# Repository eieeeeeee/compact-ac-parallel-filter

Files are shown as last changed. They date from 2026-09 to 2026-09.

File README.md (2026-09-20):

# Compact AC Parallel Filter

Compact plug-in experimental AC mains parallel network for **100 V AC, 50/60 Hz** environments.

> [!WARNING]
> ## PRE-PROTOTYPE / EXPERIMENTAL / NOT YET TESTED ON MAINS
>
> This project is currently at the **design and simulation stage only**.
>
> **No physical prototype has yet been manufactured or tested.**
>
> The schematic, PCB layout, component selection, insulation distances, enclosure, thermal behavior, surge behavior, failure modes, and noise-reduction performance have **not yet been validated on actual mains power**.
>
> This repository must **not** be interpreted as a finished, certified, production-ready, or safety-approved design.
>
> The design connects directly to hazardous mains voltage. Construction, testing, modification, or use should only be undertaken by persons with appropriate electrical-safety knowledge, equipment, and applicable regulatory review.

## Status

| Item | Current state |
|---|---|
| Version | `v0.1.1-preprototype` |
| Development stage | Design / simulation / pre-prototype |
| Target mains | 100 V AC, 50/60 Hz |
| KiCad 10 review PCB | **DRC: 0 violations / 0 unconnected pads / 0 footprint errors** |
| Physical prototype | **NOT BUILT** |
| Mains test | **NOT PERFORMED** |
| EMI/noise performance | **NOT VERIFIED** |
| Thermal test | **NOT PERFORMED** |
| Surge/fault test | **NOT PERFORMED** |
| Safety certification | **NONE** |

## Latest review material

- [KiCad hardware files](hardware/kicad/README.md)
- [KiCad 10 review PCB v0.5](hardware/kicad/review-v0.5/README.md) — 50 × 35 mm spacing/DNP study
- [KiCad 10 official DRC report](measurements/drc/DRC_KiCad10_v0_5_20260920.rpt)
- [Simulation v0.1](simulations/v0.1/simulation_assumptions_v0_1.md)
- [Editable LTspice analysis files](simulations/ltspice-v0.1/README.md) — AC sweep and post-unplug discharge
- [Simulation overview image](images/shunt_filter_simulation_overview_v0_1.png)

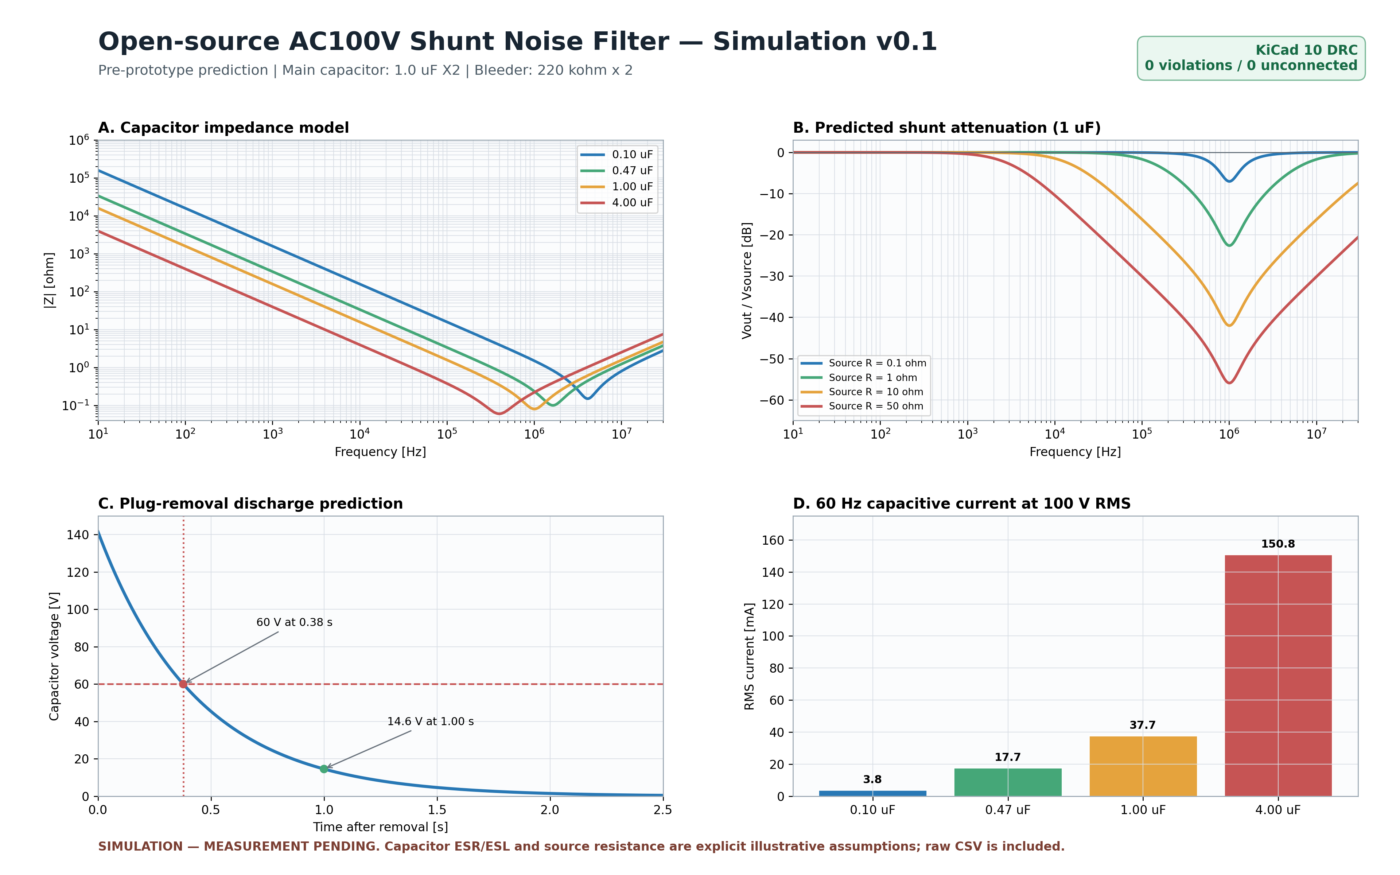
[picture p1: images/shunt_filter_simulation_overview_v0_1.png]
Pre-prototype simulation overview


The simulation figures are **predictions based on disclosed assumptions**, not measurements. In particular, high-frequency performance depends on capacitor ESR/ESL, PCB and wiring inductance, outlet/source impedance, connected equipment, and placement.

## Design target

The initial concept is a compact direct plug-in parallel network using:

- **C1:** 1 µF X2 safety capacitor — KEMET R53 series
- **R1/R2:** 220 kΩ + 220 kΩ discharge network
- **F1:** Littelfuse 37402500000, 250 mA time-lag fuse
- **MOV1:** Littelfuse TMOV14RP140E thermally protected MOV
- **LED:** low-current status indicator with reverse-voltage protection
- **CMC:** not included in the initial parallel-only architecture
- **Optional C2 / RC damping:** reserved for later measurement-based evaluation

Two PCB studies are retained for review rather than silently replacing one another:

| Revision | Board | Purpose |
|---|---:|---|
| KiCad 9 Rev.A | 32 × 28 mm | compact mechanical study |
| KiCad 10 review v0.5 | 50 × 35 mm | wider spacing and DNP comparison footprints |

Neither revision is a fabrication-approved or mains-validated design.

## Project goals

1. Design the smallest practical direct plug-in PCB without sacrificing electrical-safety margins.
2. Publish the complete design process, not only favorable results.
3. Measure the effect of the network under controlled conditions.
4. Record temperature, discharge behavior, mains current, noise spectra, and failure-related observations.
5. Revise the PCB based on measured data before calling the design validated.

## Repository structure

```text
.
├─ README.md
├─ SAFETY.md
├─ CHANGELOG.md
├─ LICENSE
├─ bom/
│  └─ BOM.md
├─ docs/
│  ├─ DESIGN_NOTES.md
│  └─ TEST_PLAN.md
├─ hardware/
│  └─ kicad/
│     ├─ README.md
│     └─ review-v0.5/
├─ simulations/
│  └─ v0.1/
├─ measurements/
│  ├─ README.md
│  └─ drc/
└─ images/
```

## Development stages

### v0.1 — Pre-prototype

- schematic development
- BOM definition
- PCB layout
- enclosure study
- creepage/clearance review
- design review before manufacturing

### v0.2 — Prototype

- first PCB manufactured
- visual inspection
- continuity/isolation checks
- controlled first power-up
- mechanical fit evaluation

### v0.3 — Measurement

- mains current
- discharge time
- thermal measurements
- oscilloscope measurements
- conducted-noise comparison
- before/after data under repeatable loads

### v0.4 — Revised prototype

PCB and BOM revised from measured results.

### v1.0 — Validated open-hardware release

Only after the defined validation work has been completed and the published documentation reflects the tested hardware revision.

## Measurement policy

Negative or null results are still results.

The project intends to publish comparable measurements for:

- baseline without the network
- 1 µF network enabled
- representative resistive/electronic loads
- 50 Hz and 60 Hz where practical
- temperature and long-duration behavior
- noise spectra using identical measurement settings

No performance claim should be made from the circuit diagram or simulation alone.

## Regulatory note

Open-source publication does **not** imply compliance with Japanese PSE requirements, IEC standards, or any other product-safety or EMC requirement. Regulatory compliance, certification, and marketability are separate questions from publication of design files.

See [SAFETY.md](SAFETY.md) before working with this design.

---

## 日本語概要

このリポジトリは、AC100 Vコンセントに直接挿す小型並列回路の**設計・計算・測定過程を公開する実験的オープンハードウェアプロジェクト**です。

**現時点では実機未製作・商用電源未試験です。完成品、安全確認済み製品、認証済み製品ではありません。**

KiCad 10用レビュー基板v0.5では公式DRCを実行し、違反0・未接続0・フットプリントエラー0を確認しました。ただし、DRC合格は回路の安全性、部品定格、絶縁、筐体、熱、サージ耐性、ノイズ低減効果を保証するものではありません。

試作前のシミュレーションでは、容量別インピーダンス、電源側インピーダンス別の減衰予測、1 µF＋440 kΩの放電曲線、AC100 V・60 Hz時の容量電流を公開しています。使用した仮定と計算用データも収録し、試作後に実測値と比較できる形にしています。

初号機を製作・測定するまでは `v0.1.1-preprototype` として扱い、実測結果は成功・不成功を問わず公開する方針です。

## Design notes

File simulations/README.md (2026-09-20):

# Simulations

Pre-prototype calculations and transparent model inputs are stored here.

## v0.1

The first dataset compares:

- impedance of 0.1 µF, 0.47 µF, 1 µF and 4 µF capacitor models
- predicted shunt attenuation for several assumed source impedances
- ideal discharge of 1 µF through 440 kΩ
- 60 Hz capacitive current at 100 V RMS

Start with [`v0.1/simulation_assumptions_v0_1.md`](v0.1/simulation_assumptions_v0_1.md) and the [overview image](../images/shunt_filter_simulation_overview_v0_1.png).

These are calculations, not measured product-performance claims. Raw CSV data, the generation script and LTspice-compatible example netlists are included for review and reproduction.

## LTspice v0.1

Editable LTspice analysis files are available in [`ltspice-v0.1/`](ltspice-v0.1/README.md):

- small-signal AC sweep with stepped source impedance
- ideal post-unplug discharge of 1 µF through 440 kΩ

The `.asc` files expose every model assumption as a SPICE directive and can be changed before rerunning the analysis.

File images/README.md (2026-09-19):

# Images

Planned contents:

- schematic preview
- PCB render
- enclosure concept
- assembled prototype photographs
- test setup photographs

Any rendered PCB or enclosure image must be clearly distinguishable from a photograph of a tested prototype.

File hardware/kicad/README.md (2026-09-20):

# KiCad hardware

This directory contains two editable PCB studies. They are kept as separate revisions because their board size and implementation choices differ.

## Revision index

| Revision | KiCad | Board | Purpose | Status |
|---|---:|---:|---|---|
| Rev.A | 9 | 32 × 28 mm | compact mechanical study | pre-prototype |
| [review-v0.5](review-v0.5/README.md) | 10 | 50 × 35 mm | spacing and optional DNP branch study | official DRC: 0 violations |

Neither revision has been manufactured or tested on mains.

## Rev.A files in this directory

- `compact-ac-parallel-filter.kicad_pro` — project
- `compact-ac-parallel-filter.kicad_sch` — schematic
- `compact-ac-parallel-filter.kicad_pcb` — exact 32 × 28 mm PCB outline
- `ACP.kicad_sym` — local symbols
- `ACP.pretty/` — project-local footprints
- `PLACEMENT.csv` — placement coordinates

## Status

**PRE-PROTOTYPE / NOT YET TESTED ON MAINS.**

These files are for design review before fabrication. No physical-fit, mains, thermal, surge, EMC, PSE, or third-party safety validation has been completed.

## Rev.A mechanical basis

- PCB: **32.0 × 28.0 mm**
- nominal PCB thickness: **1.6 mm**
- C1: 22.5 mm lead pitch, 26.5 × 10 mm top-view body envelope
- MOV1: 7.5 mm nominal lead spacing; the footprint reserves a **17 mm maximum body envelope**
- F1: 5.08 mm pitch, 8.5 mm diameter envelope
- large THT parts are on the front; low-power resistor/LED/diode parts are on the back

At 32 × 28 mm the large-part courtyards are deliberately packed to the mechanical limit. If final creepage, clearance, enclosure or tolerance review fails, increase the PCB size rather than reducing safety margin.

## J1 limitation

`J1` is **not a Japanese/Type-A plug-blade footprint**. It is a provisional electrical interface to a separately mechanically retained plug assembly. Plug insertion/removal force must not be carried only by the PCB pads.

## Before ordering

1. Choose one reviewed hardware revision; do not mix files from different revisions.
2. Apply the final mains creepage/clearance rules for the actual regulatory environment.
3. Verify enclosure and component maximum dimensions against manufacturer drawings.
4. Verify every resistor's working/pulse voltage, power and flame behavior.
5. Verify the final LED and diode part numbers.
6. Replace J1 with the final plug/enclosure mechanical interface.
7. Review fuse/MOV coordination and abnormal-condition behavior.
8. Run ERC/DRC again with the exact ordered components and manufacturing rules.

## Rev.A topology

```text
AC L -- F1 --+-- C1 1uF X2 --+-- N
             |                |
             +-- MOV1 --------+
             |                |
             +-- R1 -- R2 ----+
             |                |
             +-- R4 -- R5 -- LED1 --+
                              |      |
                              +--D1--+  reverse clamp
                                     |
                                     N
```

C2 and optional RC damping are intentionally not implemented on the 32 × 28 mm Rev.A PCB. The 50 × 35 mm review-v0.5 board provides DNP footprints for measurement-driven comparison.

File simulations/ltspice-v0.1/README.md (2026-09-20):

# LTspice simulation v0.1

This folder contains editable LTspice analysis sheets for reproducing two pre-prototype calculations.

## Files

- `shunt_filter_ac_v0_1.asc` — small-signal AC sweep of the 1 µF shunt branch
- `discharge_v0_1.asc` — ideal post-unplug discharge of 1 µF through 440 kΩ

Both files are plain-text LTspice `.asc` sheets. The circuit is defined by visible SPICE directives so that the assumed values can be reviewed and edited directly.

## 1. AC sweep

Open `shunt_filter_ac_v0_1.asc`, click **Run**, and plot:

```text
dB(V(vout)/V(vin))
```

The source resistance is stepped through:

```text
0.1 Ω, 1 Ω, 10 Ω, 50 Ω
```

The capacitor model is:

```text
C = 1 µF
ESR = 0.08 Ω
ESL = 25 nH
```

These ESR and ESL values are illustrative assumptions, not guaranteed KEMET R53 data. Replace them with measured impedance or manufacturer frequency data when available.

The 50 Ω curve is a repeatable test-fixture case. It does not mean that a household outlet has 50 Ω source impedance. Real attenuation depends on the noise source impedance, house wiring, connected equipment, placement and frequency.

The fuse, TMOV and LED branch are omitted from this linear small-signal model. Their primary roles are protection and indication; the MOV is normally non-conductive at the AC test amplitude.

## 2. Discharge

Open `discharge_v0_1.asc`, click **Run**, and plot:

```text
V(cap)
```

Nominal model:

- initial voltage: 141.421 V, equal to the peak of 100 V RMS
- C1: 1 µF
- Rbleed: 440 kΩ
- time constant: 0.44 s
- predicted crossing of 60 V: approximately 0.377 s
- predicted voltage at 1 s: approximately 14.6 V

The model is ideal and does not include component tolerance, resistor voltage coefficient, interruption phase, instrument loading or external coupling.

## Scope and safety

These files are simulations only. They do not demonstrate EMI performance, surge protection, regulatory compliance or safe mains construction. The hardware remains unbuilt and untested on mains.

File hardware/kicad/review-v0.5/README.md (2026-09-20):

# KiCad 10 review PCB v0.5

This folder contains a separate **50 × 35 mm** pre-prototype PCB study for electrical-spacing review and later A/B measurements. It does not replace the 32 × 28 mm KiCad 9 Rev.A design.

## Files

- `wall_filter_v0_5.kicad_pcb` — routed KiCad 10 PCB
- `wall_filter_v0_5.kicad_dru` — project design rules
- `fp-lib-table` — project-local footprint mapping
- `WallFilter_Custom.pretty/` — 12 local footprints
- `PCB_NOTES_v0_5.md` — revision notes and DRC summary
- `STATIC_CHECK_v0_5.txt` — independent static geometry/connectivity check

The official KiCad 10 DRC output is archived at [`measurements/drc/DRC_KiCad10_v0_5_20260920.rpt`](../../../measurements/drc/DRC_KiCad10_v0_5_20260920.rpt).

## Verification snapshot

KiCad 10 official DRC, 2026-09-20:

- DRC violations: **0**
- unconnected pads: **0**
- footprint errors: **0**

Static checker:

- pads checked: 26
- routed segments checked: 23
- reported minimum L/L_FUSED-to-N copper spacing: 4.5 mm
- reported minimum copper-to-rectangular-board-boundary distance: 2.0 mm

These checks verify the rules and geometry represented in the files; they do **not** establish regulatory compliance or safety on mains.

## Implemented branches

- fused L input
- C1: 1 µF X2 main shunt capacitor
- R1 + R2: 220 kΩ + 220 kΩ discharge chain
- MOV1: 140 VAC thermally protected MOV candidate
- low-current LED branch and antiparallel protection diode
- C2: optional 0.1 µF X2 footprint, **DNP initially**
- R3/C3: optional series RC damping footprint, **DNP initially**

## Required review before fabrication or energization

- Match every footprint to the exact manufacturer drawing and ordered part.
- Confirm voltage, pulse, power, flammability and safety approvals for each part.
- Review creepage/clearance for the final material, pollution degree, enclosure and applicable standard.
- Finalize plug blades, retention, enclosure, insulation and accessible-part protection as one mechanical system.
- Review fuse clearing and TMOV coordination under credible faults.
- Perform unpowered continuity/insulation checks before any controlled mains test.

**PRE-PROTOTYPE / NOT YET BUILT / NOT YET TESTED ON MAINS.**

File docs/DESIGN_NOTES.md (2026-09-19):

# Design Notes

## Project architecture

The initial version is a **direct plug-in parallel network** connected across 100 V AC mains.

It is not a pass-through power filter and has no downstream outlet or load path.

## Preliminary topology

After the input fuse, the following branches are intended to be connected across line and neutral:

- 1 µF X2 capacitor
- 220 kΩ + 220 kΩ discharge resistor chain
- thermally protected MOV
- low-current indicator LED branch
- optional DNP X2 capacitor footprint
- optional DNP RC damping footprint

## Why no CMC in v0.1

A conventional common-mode choke is normally placed in series with line and neutral feeding a load. In the present one-port parallel-only architecture there is no downstream current path through such a choke.

Therefore a CMC is intentionally omitted from the first design.

## Mechanical target

### PCB

Target: **approximately 32 × 28 mm**

This is a size goal, not a mandatory limit.

The PCB must be enlarged if necessary to satisfy:

- creepage/clearance requirements
- component body spacing
- fuse/MOV placement
- thermal behavior
- routing
- manufacturing tolerances
- plug mechanics

### Enclosure

Target: **approximately 38 × 34 × 27 mm**

The enclosure is expected to use vertical component volume efficiently because the X2 capacitor and 14 mm MOV are physically larger than most remaining parts.

## Component placement priorities

1. Fuse near the mains input.
2. MOV electrically after the fuse.
3. Keep high-current surge paths short.
4. Place C1 and its discharge resistors close together.
5. Keep mains-connected copper away from enclosure openings and accessible surfaces.
6. Do not use dense copper pours merely to reduce routing length.
7. Reserve sufficient edge spacing around the PCB perimeter.

## Electrical observations

A 1 µF capacitor across 100 V AC carries a nominal reactive current of approximately:

- 31 mA at 50 Hz
- 38 mA at 60 Hz

This is reactive current, not equivalent real power dissipation, but it is relevant to component stress and circuit behavior.

## Version policy

The project remains **pre-prototype** until a physical unit is assembled.

No efficiency, EMI-reduction, surge-protection, thermal, or safety-performance claim should be made before measurement.

## KiCad Rev.A implementation

The first editable PCB study is committed under `hardware/kicad/`.

### Exact board outline

**32.0 × 28.0 mm**, nominal 1.6 mm FR-4.

### Placement strategy

Front side:
- C1 — KEMET R53 1 µF X2
- MOV1 — TMOV14RP140E
- F1 — Littelfuse 37402500000
- J1 — provisional connection pads to a separately retained plug assembly

Back side:
- R1/R2 — discharge network
- R4/R5 — LED current limiting
- LED1
- D1 — reverse clamp

Moving the low-power components to B.Cu is what makes the 32 × 28 mm target mechanically plausible.

### Mechanical limit

The C1 courtyard and the 17 mm maximum TMOV body courtyard are effectively packed to the board-size limit. The 32 × 28 mm outline is therefore a **fit study, not a guaranteed production envelope**.

### Plug interface

The current J1 footprint is deliberately not presented as a Japanese Type-A blade footprint. The final plug blade geometry, blade retention and enclosure must be selected as one mechanical system. Plug insertion/removal forces must not rely only on soldered PCB pads.

### Parts still requiring qualification

- exact 220 kΩ 1206 resistor
- exact 47 kΩ 1206 resistor
- exact blue 1206 LED
- exact SOD-123 reverse diode
- final plug/enclosure assembly

The exact resistor parts must satisfy the required voltage, overload/pulse, power and flame-performance requirements for the final product.

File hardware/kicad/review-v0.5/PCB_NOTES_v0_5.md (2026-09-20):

# PCB v0.5 — KiCad 10 DRC警告整理版

## v0.4のKiCad 10公式DRC結果

2026-09-20にKiCad 10で出力されたレポートを確認しました。

- DRCエラー：0
- 未接続パッド：0
- フットプリントエラー：0
- 警告：28

28件は、基板端または銅箔と重なるシルク、シルク同士の重なり、および `Custom` フットプリントライブラリ未登録に関するものでした。電気配線のエラーは報告されていません。

## v0.5の変更点

- `WallFilter_Custom.pretty` に12個のプロジェクト専用フットプリントを収録
- `fp-lib-table` で上記ライブラリを `${KIPRJMOD}` 相対パス登録
- 部品外形線をF.SilkS/B.SilkSからF.Fab/B.Fabへ移動
- 重なっていた部品参照文字を非表示化
- 回路・ネット・部品位置・銅箔配線・基板外形はv0.4から変更なし
- v0.5静的検査：PASS

## 次の確認

1. `wall_filter_v0_5.kicad_pcb` をKiCad 10で開く
2. プロジェクト・フットプリント・ライブラリの登録を求められた場合はプロジェクト固有として承認
3. 「検査」→「デザインルールチェッカー」→「DRCを実行」
4. エラー、警告、未接続が0であることを確認
5. 新しいDRCレポートを保存

v0.5の静的検査では、全26パッドの接続、異ネット銅箔の非重複、L/L_FUSED-N最小4.5mm、銅箔-基板端最小2.0mmを確認しています。KiCad 10公式DRCの再実行をもって警告整理の最終確認とします。

## KiCad 10公式DRC再確認

2026-09-20 11:06（JST）に `wall_filter_v0_5.kicad_pcb` の公式DRCを再実行しました。

- DRC違反：0
- 未接続パッド：0
- フットプリントエラー：0

これにより、v0.5はKiCad 10のDRC確認を通過しました。次工程は、実部品データシートとの外形・定格照合、シミュレーション、筐体干渉確認、試作後の通電前検査です。

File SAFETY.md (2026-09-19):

# Safety

## Hazardous mains voltage

This project is intended to connect directly to **100 V AC mains**. Mains voltage can cause electric shock, burns, fire, equipment damage, or death.

This repository is currently **pre-prototype**. No physical unit has yet been built or validated.

## Current project status

- Physical prototype: **not built**
- Mains powered test: **not performed**
- Thermal test: **not performed**
- Surge/fault test: **not performed**
- Insulation verification: **not completed on hardware**
- Regulatory compliance: **not established**
- Safety certification: **none**

Do not treat any schematic, PCB, BOM, enclosure dimension, or layout in this repository as inherently safe merely because it is published here.

## Design rules for the project

The following are project requirements, not a certification statement:

1. Do not reduce creepage or clearance merely to meet the nominal 32 × 28 mm PCB target.
2. If adequate spacing cannot be maintained, increase the PCB or enclosure size.
3. Keep exposed mains-connected copper inaccessible in the completed enclosure.
4. The plug structure must carry insertion/removal forces mechanically; the PCB should not be used as the sole structural support for plug blades.
5. Use only appropriately rated components for mains-connected positions.
6. Do not substitute ordinary capacitors for X-class safety capacitors.
7. Review fuse and MOV coordination before prototype power-up.
8. Verify discharge voltage after unplugging.
9. Perform first energization using appropriate current limiting, protection, isolation strategy, and test equipment suitable for mains work.
10. Treat oscilloscope grounding and other earth-referenced instruments as potential short-circuit hazards when measuring non-isolated mains circuitry.

## Enclosure

The target enclosure size is approximately **38 × 34 × 27 mm**, but size is secondary to:

- creepage and clearance
- insulation
- flame resistance
- mechanical plug retention
- component temperature
- user inaccessibility to live parts

## Regulatory note

This repository does not claim conformity with PSE, IEC, JIS, UL, CE, or other standards. If the design is ever manufactured, distributed, or sold, the applicable legal and technical requirements must be determined separately.

## Responsibility

Anyone building or modifying this design is responsible for performing their own engineering, safety, and regulatory review.

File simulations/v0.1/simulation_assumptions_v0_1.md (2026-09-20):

# Simulation v0.1 — assumptions and interpretation

## Status

These figures are pre-prototype calculations, not measured performance. They are intended to expose the model and invite review before parts are ordered. The final repository will retain these predictions alongside measured results.

## Capacitor impedance model

Each capacitor is represented by an ideal capacitance in series with illustrative ESR and ESL:

| Nominal capacitance | ESR | ESL |
|---:|---:|---:|
| 0.10 µF | 0.15 Ω | 15 nH |
| 0.47 µF | 0.10 Ω | 20 nH |
| 1.00 µF | 0.08 Ω | 25 nH |
| 4.00 µF | 0.06 Ω | 40 nH |

These are transparent engineering assumptions, not guaranteed values for the selected KEMET R53 part. They must be replaced or bounded using measured impedance or manufacturer frequency data.

## Attenuation model

The filter is modeled as a shunt impedance across L-N, driven through a purely resistive Thevenin source impedance of 0.1, 1, 10, or 50 Ω. The predicted voltage ratio is:

`H(f) = Zfilter(f) / (Zsource + Zfilter(f))`

The 50 Ω curve represents a convenient test-fixture condition; it is not a claim that a household outlet has 50 Ω source impedance. Real attenuation depends on wiring, connected equipment, noise-source impedance, placement, and frequency.

## Discharge model

- Supply: 100 V RMS
- Initial capacitor voltage: 141.4 V peak
- C1: 1.0 µF
- Bleeder: 220 kΩ × 2 series = 440 kΩ
- Time constant: 0.44 s
- Ideal exponential discharge: `V(t) = 141.4 exp(-t/0.44)`

Component tolerance, resistor voltage coefficient, interruption timing, and residual source coupling are not included.

## 60 Hz current

The plot uses ideal capacitive current `I = 2πfCV` at 100 V RMS and 60 Hz. It is reactive current, not equivalent to real power consumption.

## Safety scope

Simulation does not establish regulatory compliance or safe construction. Before energized use, the assembled prototype requires enclosure, insulation, strain relief, temperature, abnormal-condition, fuse-clearing, dielectric-strength, and controlled mains-measurement review.

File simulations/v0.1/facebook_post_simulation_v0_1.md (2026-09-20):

# Facebook掲載文案

挿すだけ並列型ノイズフィルターの試作前シミュレーションを公開しました。

今回掲載したのは、0.1µF・0.47µF・1µF・4µFの容量別インピーダンス、1µFを使用した場合の電源側インピーダンス別の減衰予測、プラグを抜いた後の放電曲線、AC100V・60Hzにおける容量電流の比較です。

現在の基準回路は、1µFのX2安全コンデンサー、220kΩ×2本の放電抵抗、ヒューズ、熱保護付きMOV、通電表示回路で構成しています。KiCad 10の基板DRCは、違反0・未接続0・フットプリントエラー0になりました。

掲載値は実測結果ではなく、試作前の予測値です。特に高周波特性は、コンデンサーのESR・ESL、基板配線、コンセント側や接続機器側のインピーダンスによって変化します。そのため、今回使用した仮定と計算用データもGitHubに公開し、試作後は実測値と比較できる形にします。

単に「効果がある・ない」で終わらせず、どの条件で、どの周波数に、どれくらい作用するのかを確認できるオープンハードウェアとして進めたいと考えています。モデルや測定方法についてお気づきの点があれば、ぜひご意見をお願いいたします。

※AC100Vを扱うため、現段階は設計・シミュレーション・安全検証中です。試作後も、絶縁、温度、放電時間、異常時保護などを確認してから通電評価へ進みます。

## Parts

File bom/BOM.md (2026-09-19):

# Preliminary BOM — v0.1.0-preprototype / KiCad Rev.A

**Status:** design-stage BOM only.  
**Prototype manufactured:** no.  
**Mains tested:** no.

| Ref | Part / target specification | Qty | PCB implementation | Status |
|---|---|---:|---|---|
| F1 | Littelfuse **37402500000** | 1 | THT, 5.08 mm pitch | Selected candidate |
| C1 | KEMET **R533N410050P0K** / R53 | 1 | THT, 22.5 mm pitch | Selected |
| R1, R2 | **220 kΩ each** | 2 | **1206 SMD on B.Cu** | Exact mains-qualified part TBD |
| MOV1 | Littelfuse **TMOV14RP140E** | 1 | THT, 7.5 mm nominal pitch | Selected candidate |
| R4, R5 | **47 kΩ each** | 2 | **1206 SMD on B.Cu** | Exact mains-qualified part TBD |
| LED1 | blue LED | 1 | 1206 SMD on B.Cu | Exact part TBD |
| D1 | **1N4148W-class** reverse clamp | 1 | SOD-123 on B.Cu | Exact part TBD |
| J1 | plug-assembly electrical interface | 1 | two THT pads, 10 mm pitch | **Provisional; not plug blades** |
| C2 | 0.1 µF X2 | 0 | no footprint on Rev.A | Future measurement variant |
| R3/C3 | RC damping network | 0 | no footprint on Rev.A | Future measurement variant |
| PCB | FR-4, **32 × 28 mm** | 1 | KiCad Rev.A | Pre-prototype |

## Important BOM limitations

The 1206 resistor footprint is fixed for the current compact layout, but the **actual resistor manufacturer/series is not yet fixed**. The selected components must be checked for working voltage, overload/pulse voltage, power dissipation, flame behavior and applicable approvals before fabrication.

The same applies to LED1 and D1: the footprint and function are defined, but the exact orderable part numbers remain to be selected.

## Discharge network

R1 + R2 = 440 kΩ nominal across C1.

With C1 = 1 µF, the nominal RC time constant is approximately **0.44 s**. Actual post-unplug voltage decay must be measured on the physical prototype.

## Compact Rev.A exclusions

C2 and the optional RC damping branch are intentionally omitted from the 32 × 28 mm PCB. Adding them is deferred until measurements show a reason to do so.

A common-mode choke is not included because this is a one-port parallel architecture rather than a pass-through filter.

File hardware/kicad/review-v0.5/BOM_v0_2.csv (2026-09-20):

Ref | Qty | Initial | Manufacturer | MPN | Value_or_rating | Role | Notes
C1 | 1 | Fitted | KEMET | R533N410050P0K | 1uF X2 310VAC | Main shunt capacitor | 22.5mm lead pitch
R1 R2 | 2 | Fitted | Vishay | PR01000102203JA100 | 220k 1W 5% | Discharge path | Series total 440k
F1 | 1 | Fitted | Littelfuse | 37402500000 | 250mA 250VAC time-lag | Fault isolation | Radial PCB fuse
MOV1 | 1 | Fitted | Littelfuse | TMOV14RP140E | 140VAC thermally protected MOV | Surge protection | Placed after F1
R4 R5 | 2 | Fitted | Vishay | PR01000104702JA100 | 47k 1W 5% | LED current limiting | Series total 94k
D1 | 1 | Fitted | Generic | 1N4007 | 1000V rectifier diode | LED reverse-voltage clamp | Antiparallel with LED1
LED1 | 1 | TBD | TBD | TBD | 3mm blue low-current high-efficiency | Power indication | Keep behind case window
C2 | 1 | DNP | TBD | TBD | 0.1uF X2 305VAC | High-frequency comparison | Populate only after measurement
R3 C3 | 1 set | DNP | TBD | TBD | Measurement-defined | RC damping branch | Values selected from impedance measurement
J1 | 1 | Mechanical TBD | TBD | TBD | Two-blade AC100V plug interface | Final metal blade retention not yet fixed

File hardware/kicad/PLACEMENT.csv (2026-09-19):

Ref | Side | X_mm | Y_mm | Rotation_deg | Footprint | Status
J1 | F | 124.5 | 125.5 | 0 | ACP:AC_Input_Pads_10mm | PROVISIONAL_NOT_BLADE
F1 | F | 123.5 | 115.2 | 0 | ACP:TR5_374_5.08mm | PREPROTO
C1 | F | 116.0 | 105.25 | 0 | ACP:R53_1uF_22.5mm | PREPROTO
MOV1 | F | 108.75 | 119.25 | 0 | ACP:TMOV14_7.5mm | PREPROTO
R1 | B | 106.0 | 102.8 | 0 | ACP:R_1206 | PART_TBD
R2 | B | 112.0 | 102.8 | 0 | ACP:R_1206 | PART_TBD
R4 | B | 106.0 | 107.5 | 0 | ACP:R_1206 | PART_TBD
R5 | B | 112.0 | 107.5 | 0 | ACP:R_1206 | PART_TBD
LED1 | B | 120.0 | 107.5 | 0 | ACP:LED_1206 | PART_TBD
D1 | B | 120.0 | 110.4 | 180 | ACP:D_SOD123 | PART_TBD

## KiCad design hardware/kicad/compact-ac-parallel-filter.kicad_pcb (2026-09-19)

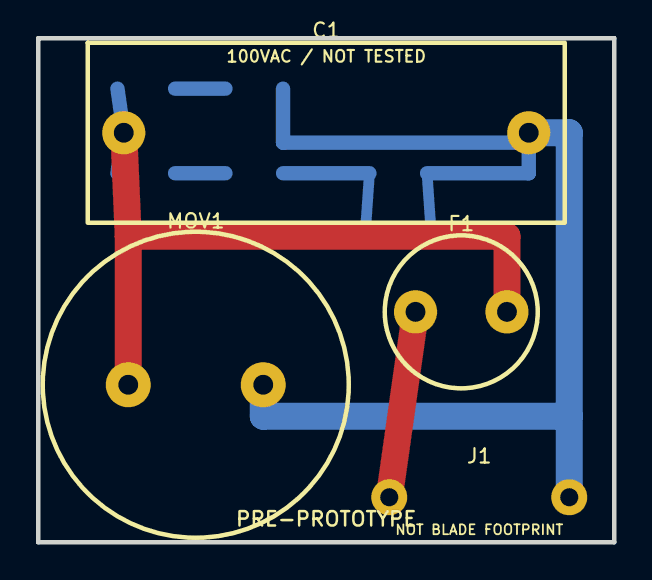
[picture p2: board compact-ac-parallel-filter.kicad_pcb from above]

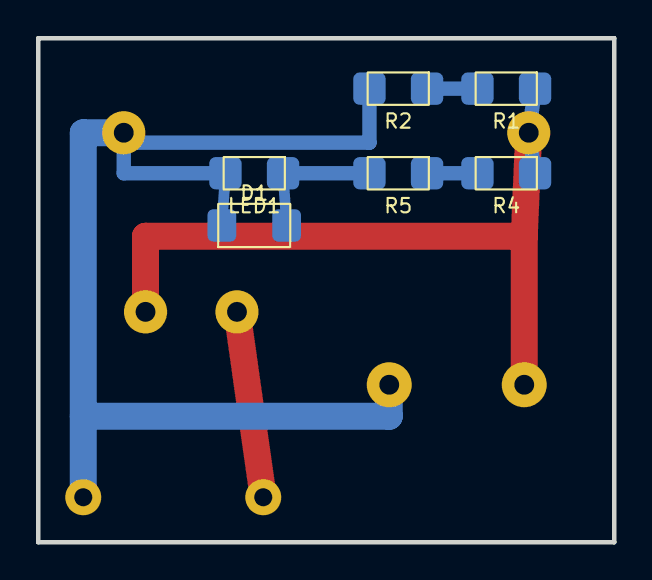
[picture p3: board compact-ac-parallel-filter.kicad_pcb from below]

Board: 2 copper layers, 32.0 x 28.0 mm, 10 parts (6 on the bottom side), 6 nets.

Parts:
C1: R533N410050P0K; R53_1uF_22.5mm
D1: 1N4148W reverse clamp; D_SOD123
F1: 37402500000; TR5_374_5.08mm
J1: PROVISIONAL PLUG INTERFACE; AC_Input_Pads_10mm
LED1: Blue LED; LED_1206
MOV1: TMOV14RP140E; TMOV14_7.5mm
R1, R2: 220k; R_1206
R4, R5: 47k; R_1206

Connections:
AC_L: F1.1, J1.1 (L)
DISCH_MID: R1.2, R2.1
LED_A: D1.2 (K), LED1.1 (A), R5.2
LED_RMID: R4.2, R5.1
L_FUSED: C1.1, F1.2, MOV1.1, R1.1, R4.1
N: C1.2, D1.1 (A), J1.2 (N), LED1.2 (K), MOV1.2, R2.2

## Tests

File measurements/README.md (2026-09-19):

# Measurements

This directory will contain measurements from physical prototypes.

## Current status

**No prototype has been built. No measurements exist yet.**

Planned categories include:

- discharge-voltage measurements
- RMS current
- thermal measurements
- oscilloscope captures
- conducted-noise comparisons
- long-duration observations
- failure or abnormal-behavior reports

Raw data should be retained whenever practical.

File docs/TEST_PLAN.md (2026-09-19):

# Test Plan

## Purpose

This document defines the minimum evidence required before the project can move from **pre-prototype** to a tested hardware revision.

## Stage 0 — Before mains connection

- Visual PCB inspection
- Confirm component values and part numbers
- Verify fuse continuity
- Verify no line-to-neutral hard short
- Verify no accidental copper bridges
- Verify polarity/orientation-sensitive parts
- Verify MOV footprint and pin assignment
- Verify LED protection diode orientation
- Measure resistance across input
- Inspect creepage and clearance against the design review
- Inspect enclosure and plug retention
- Confirm no live conductor can be touched from outside

## Stage 1 — Controlled first energization

Perform only with suitable mains safety equipment and engineering controls.

Record:

- input RMS voltage
- input RMS current
- immediate abnormal heating
- audible noise
- odor/smoke
- LED behavior
- fuse behavior
- voltage across C1

If any abnormal condition occurs, disconnect and document it before revising the design.

## Stage 2 — Discharge test

After disconnecting mains:

- measure voltage versus time
- compare measured decay against the nominal RC model
- repeat over multiple cycles
- document instrument impedance because it can alter the measured discharge

## Stage 3 — Thermal test

Measure temperature of:

- C1
- F1
- MOV1
- R1/R2
- LED resistors
- enclosure internal air
- enclosure external surface

Suggested checkpoints:

- 5 min
- 30 min
- 1 h
- extended run if initial temperatures are stable

Record ambient temperature.

## Stage 4 — Electrical measurements

Measure:

- RMS mains current
- real power if suitable equipment is available
- power factor if suitable equipment is available
- waveform with circuit absent/present
- repeatability over multiple plug-in cycles

## Stage 5 — Noise comparison

The central comparison must use identical measurement settings.

Minimum data sets:

1. baseline — device absent
2. device connected
3. optional C2 fitted, if tested
4. optional RC damping fitted, if tested

Use representative loads, for example:

- no local load / ambient line condition
- switching power supply
- LED lamp
- other repeatable electronic load

For each measurement, record:

- instrument
- probe/coupling method
- bandwidth
- sampling settings
- load
- mains frequency
- time/date
- raw files where possible

## Stage 6 — Mechanical review

Check:

- plug insertion/removal force
- enclosure deformation
- PCB movement
- strain on solder joints
- clearances after assembly
- part movement after repeated plugging cycles

## Stage 7 — Revision decision

A new hardware revision should be created whenever a component value, footprint, routing, spacing, enclosure, or protection strategy changes.

Do not silently modify a tested revision.

## Publication policy

Publish null, negative, and unexpected results as well as favorable results.

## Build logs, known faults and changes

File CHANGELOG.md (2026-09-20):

# Changelog

All notable design changes should be documented here.

## [0.1.1-preprototype] — 2026-09-20

### Added

- Separate KiCad 10 review PCB v0.5 under `hardware/kicad/review-v0.5/`
- Project-local footprint library and design-rule file for v0.5
- Archived official KiCad 10 DRC report
- Simulation v0.1 assumptions, CSV data, plots, generation script and example SPICE netlists
- Simulation overview image for design review
- Editable LTspice `.asc` files for AC sweep and post-unplug discharge analysis
- LTspice instructions, expected nominal checkpoints and model limitations

### Verified

- KiCad 10 v0.5 DRC: 0 violations
- KiCad 10 v0.5 unconnected pads: 0
- KiCad 10 v0.5 footprint errors: 0

### Clarified

- The KiCad 9 Rev.A 32 × 28 mm compact study and KiCad 10 v0.5 50 × 35 mm review study are separate revisions.
- Simulation results are disclosed predictions, not mains measurements or performance certification.
- The project remains pre-prototype and has not been energized on mains.

## [0.1.0-preprototype] — 2026-09-19

### Added

- Initial public repository structure
- Pre-prototype safety notice
- Preliminary BOM
- Design notes
- Prototype test plan
- KiCad workspace placeholder
- Measurement workspace placeholder

### Preliminary design target

- 100 V AC, 50/60 Hz
- PCB target: approximately 32 × 28 mm
- enclosure target: approximately 38 × 34 × 27 mm
- C1: 1 µF X2
- discharge network: 220 kΩ + 220 kΩ
- compact 250 mA time-lag fuse
- thermally protected MOV
- low-current blue status LED
- no CMC in the initial parallel-only topology

### Validation status

No physical prototype has been manufactured or mains-tested.

### KiCad Rev.A 32 × 28 mm hardware added

- Added editable KiCad 9 schematic and PCB
- Fixed PCB outline at 32 × 28 mm for the current mechanical study
- Added project-local symbols and footprints
- Placed C1, MOV1 and F1 on the front
- Moved low-power resistors, LED and clamp diode to B.Cu
- Added placement CSV
- Marked J1 as a provisional plug-assembly interface, not a final blade footprint
- Removed C2/RC footprints from this compact revision pending measurements

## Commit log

2026-09-19 docs: add pre-prototype project README
2026-09-19 docs: add preliminary BOM
2026-09-19 docs: add prototype validation plan
2026-09-19 docs: add KiCad workspace placeholder
2026-09-19 hardware: add compact-ac-parallel-filter.kicad_sch
    [compact-ac-parallel-filter.kicad_sch]
2026-09-19 hardware: add compact-ac-parallel-filter.kicad_pcb
    [compact-ac-parallel-filter.kicad_pcb]
2026-09-19 hardware: add compact-ac-parallel-filter.kicad_pro
2026-09-19 hardware: add ACP.kicad_sym
2026-09-19 hardware: add PLACEMENT.csv
    [PLACEMENT.csv]
2026-09-19 hardware: add R53_1uF_22.5mm.kicad_mod
2026-09-19 hardware: add TMOV14_7.5mm.kicad_mod
2026-09-19 hardware: add TR5_374_5.08mm.kicad_mod
2026-09-19 hardware: add AC_Input_Pads_10mm.kicad_mod
2026-09-19 hardware: add R_1206.kicad_mod
2026-09-19 hardware: add LED_1206.kicad_mod
2026-09-19 hardware: add D_SOD123.kicad_mod
2026-09-19 hardware: document 32x28 mm KiCad Rev.A pre-prototype
2026-09-19 docs: link KiCad Rev.A pre-prototype
2026-09-19 bom: align with 32x28 KiCad Rev.A
2026-09-19 docs: record KiCad Rev.A hardware addition
2026-09-20 docs: publish KiCad 10 review and simulation v0.1
    [BOM_v0_2.csv, attenuation_model_v0_1.csv, discharge_model_v0_1.csv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]
2026-10-15 Add RC18 E27N KiCad 10 native ERC/DRC nonfabrication review branch
2026-10-15 Pin RC18 E27N native verification to official KiCad 10.0.6 Docker image
2026-10-15 Initialize official KiCad 10.0.6 global symbol and footprint tables in isolated runner
2026-10-15 Archive exact Native KiCad 10.0.6 E27N ERC DRC findings (NONFAB HOLD)
2026-10-15 E27P nonfab fix NC pins and R304 DNP attributes; re-audit via KiCad 10.0.6
2026-10-15 Document KiCad 10.0.6 E27P ERC0 and PV R304 DNP fix, manufacturing HOLD
2026-10-15 Document E27Q safety-preserving simplification before PCB layout (HOLD)
2026-10-15 Record E27Q KiCad BOM source integrity and zero confirmed design savings
2026-10-15 Record P02 5V vs present 7V rail requirement reconciliation in E27Q hold
